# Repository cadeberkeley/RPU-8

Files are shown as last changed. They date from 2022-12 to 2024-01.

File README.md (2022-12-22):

# RPU-8
8-Bit Retro Processing Unit

Started on breadboards, inspired by Ben Eater's 8-bit CPU.  I got it more or less working on breadboards, and I am currently designing PCBs to make it more permanent and hopefully solve any power distribution or connection issues with the breadboard design.  I have sketched out a modular stacking design, so it will be easier to swap out for larger instruction/data memory or a larger program counter if I so please.

I am using KiCAD for schematic and PCB design.  Planning to source PCBs from JLCPCB.

TODO: Add images of breadboard.

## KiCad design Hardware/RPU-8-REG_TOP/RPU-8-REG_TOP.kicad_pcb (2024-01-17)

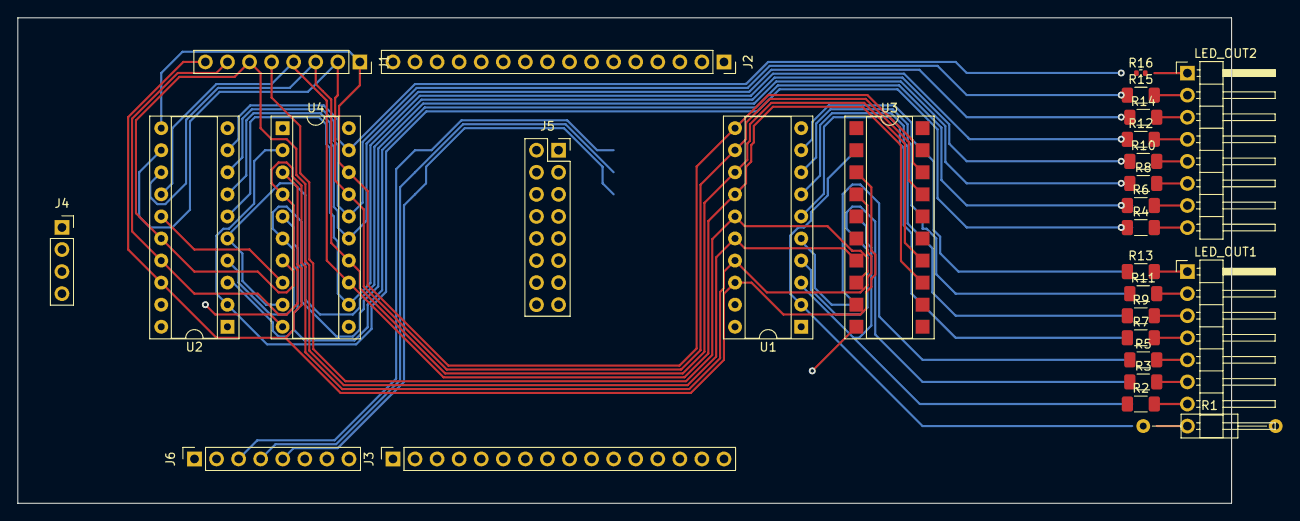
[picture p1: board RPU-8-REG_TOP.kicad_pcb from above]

Board: 2 copper layers, 139.7 x 55.9 mm, 28 parts (0 on the bottom side), 47 nets.

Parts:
J1: DATA_BUS; PinSocket_1x08_P2.54mm_Vertical
J2: ADDR_BUS; PinSocket_1x16_P2.54mm_Vertical
J3: CTRL_BUS; PinSocket_1x16_P2.54mm_Vertical
J4: Conn_01x03_Female; PinSocket_1x04_P2.54mm_Vertical
J5: REG_CTRL; PinSocket_2x08_P2.54mm_Vertical
J6: INST_BITS; PinSocket_1x08_P2.54mm_Vertical
LED_OUT1, LED_OUT2: LEDs; PinHeader_1x08_P2.54mm_Horizontal
R1: 220Ω; R_Axial_DIN0207_L6.3mm_D2.5mm_P15.24mm_Horizontal
R2, R3, R4, R5, R6, R7, R8, R9, R10, R11, R12, R13, R14, R15: 220Ω; R_1206_3216Metric_Pad1.30x1.75mm_HandSolder
R16: 220Ω; R_0402_1005Metric
U1, U2: 74HC245; DIP-20_W7.62mm_Socket
U3: 74HC377; DIP-20_W7.62mm_SMDSocket_SmallPads
U4: 74HC377; DIP-20_W7.62mm_Socket

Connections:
+5V: J4.3, U1.1 (A->B), U1.20 (VCC), U2.1 (A->B), U2.20 (VCC), U3.20 (VCC), U4.20 (VCC)
CLK: J4.1, U3.11 (CP), U4.11 (CP)
D0: J1.1, U1.11 (B7), U2.11 (B7), U3.18 (D7), U4.18 (D7)
D1: J1.2, U1.12 (B6), U2.12 (B6), U3.17 (D6), U4.17 (D6)
D2: J1.3, U1.13 (B5), U2.13 (B5), U3.14 (D5), U4.14 (D5)
D3: J1.4, U1.14 (B4), U2.14 (B4), U3.13 (D4), U4.13 (D4)
D4: J1.5, U1.15 (B3), U2.15 (B3), U3.8 (D3), U4.8 (D3)
D5: J1.6, U1.16 (B2), U2.16 (B2), U3.7 (D2), U4.7 (D2)
D6: J1.7, U1.17 (B1), U2.17 (B1), U3.4 (D1), U4.4 (D1)
D7: J1.8, U1.18 (B0), U2.18 (B0), U3.3 (D0), U4.3 (D0)
GND: J4.2, U1.10 (GND), U2.10 (GND), U3.10 (GND), U4.10 (GND)
unnamed: LED_OUT1.1 (R0), R13.2
unnamed: LED_OUT1.2 (R1), R11.2
unnamed: LED_OUT1.3 (R2), R9.2
unnamed: LED_OUT1.4 (R3), R7.2
unnamed: LED_OUT1.5 (R4), R5.2
unnamed: LED_OUT1.6 (R5), R3.2
unnamed: LED_OUT1.7 (R6), R2.2
unnamed: LED_OUT1.8 (R7), R1.2
unnamed: LED_OUT2.1 (R0), R16.2
unnamed: LED_OUT2.2 (R1), R15.2
unnamed: LED_OUT2.3 (R2), R14.2
unnamed: LED_OUT2.4 (R3), R12.2
unnamed: LED_OUT2.5 (R4), R10.2
unnamed: LED_OUT2.6 (R5), R8.2
unnamed: LED_OUT2.7 (R6), R6.2
unnamed: LED_OUT2.8 (R7), R4.2
unnamed: R1.1, U1.2 (A0), U3.2 (Q0)
unnamed: R2.1, U1.3 (A1), U3.5 (Q1)
unnamed: R3.1, U1.4 (A2), U3.6 (Q2)
unnamed: R4.1, U2.2 (A0), U4.2 (Q0)
unnamed: R5.1, U1.5 (A3), U3.9 (Q3)
unnamed: R6.1, U2.3 (A1), U4.5 (Q1)
unnamed: R7.1, U1.6 (A4), U3.12 (Q4)
unnamed: R8.1, U2.4 (A2), U4.6 (Q2)
unnamed: R9.1, U1.7 (A5), U3.15 (Q5)
unnamed: R10.1, U2.5 (A3), U4.9 (Q3)
unnamed: R11.1, U1.8 (A6), U3.16 (Q6)
unnamed: R12.1, U2.6 (A4), U4.12 (Q4)
unnamed: R13.1, U1.9 (A7), U3.19 (Q7)
unnamed: R14.1, U2.7 (A5), U4.15 (Q5)
unnamed: R15.1, U2.8 (A6), U4.16 (Q6)
unnamed: R16.1, U2.9 (A7), U4.19 (Q7)
~R0_IN: J5.1, U3.1 (~E)
~R0_OUT: J5.2, U1.19 (CE)
~R1_IN: J5.3, U4.1 (~E)
~R1_OUT: J5.4, U2.19 (CE)

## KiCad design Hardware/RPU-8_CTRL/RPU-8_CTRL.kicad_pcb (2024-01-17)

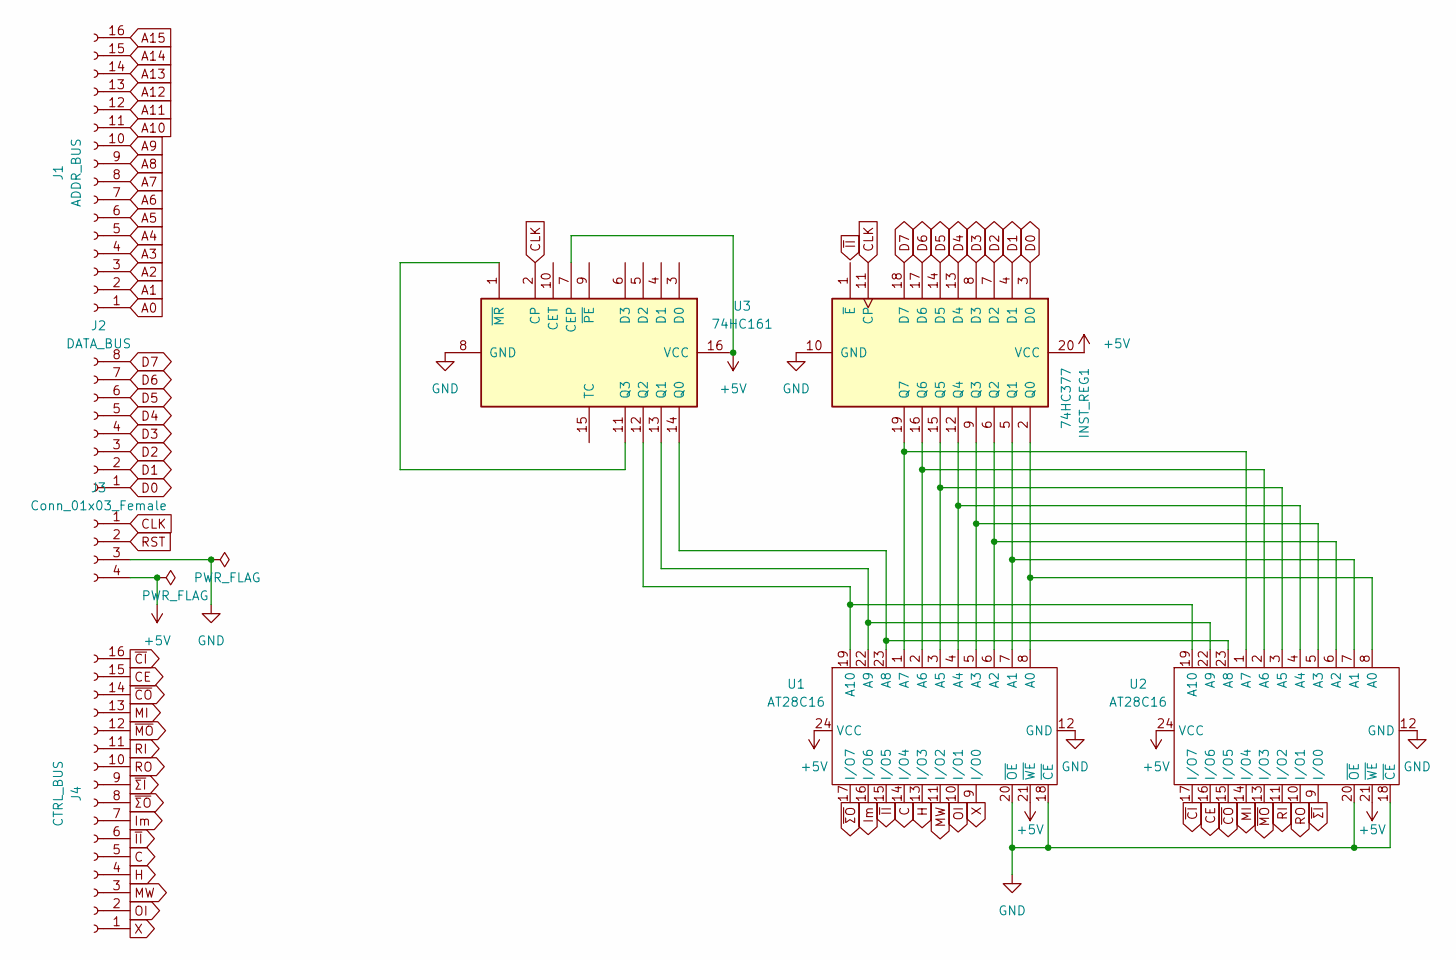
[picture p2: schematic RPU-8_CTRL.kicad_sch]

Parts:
INST_REG1: 74HC377; DIP-20_W7.62mm_Socket
J1: ADDR_BUS; PinSocket_1x16_P2.54mm_Vertical
J2: DATA_BUS; PinSocket_1x08_P2.54mm_Vertical
J3: Conn_01x03_Female; PinSocket_1x04_P2.54mm_Vertical
J4: CTRL_BUS; PinSocket_1x16_P2.54mm_Vertical
U1, U2: AT28C16; DIP-24_W15.24mm_Socket
U3: 74HC161; DIP-16_W7.62mm_Socket

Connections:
+5V: INST_REG1.20 (VCC), J3.4, U1.21 (~WE), U1.24 (VCC), U2.21 (~WE), U2.24 (VCC), U3.7 (CEP), U3.16 (VCC)
A0: J1.1
A1: J1.2
A2: J1.3
A3: J1.4
A4: J1.5
A5: J1.6
A6: J1.7
A7: J1.8
A8: J1.9
A9: J1.10
A10: J1.11
A11: J1.12
A12: J1.13
A13: J1.14
A14: J1.15
A15: J1.16
C: J4.5, U1.14 (I/O4)
CE: J4.15, U2.16 (I/O6)
CLK: INST_REG1.11 (CP), J3.1, U3.2 (CP)
D0: INST_REG1.3 (D0), J2.1
D1: INST_REG1.4 (D1), J2.2
D2: INST_REG1.7 (D2), J2.3
D3: INST_REG1.8 (D3), J2.4
D4: INST_REG1.13 (D4), J2.5
D5: INST_REG1.14 (D5), J2.6
D6: INST_REG1.17 (D6), J2.7
D7: INST_REG1.18 (D7), J2.8
GND: INST_REG1.10 (GND), J3.3, U1.12 (GND), U1.18 (~CE), U1.20 (~OE), U2.12 (GND), U2.18 (~CE), U2.20 (~OE), U3.8 (GND)
H: J4.4, U1.13 (I/O3)
Im: J4.7, U1.16 (I/O6)
MI: J4.13, U2.14 (I/O4)
MW: J4.3, U1.11 (I/O2)
unnamed: INST_REG1.19 (Q7), U1.1 (A7), U2.1 (A7)
unnamed: INST_REG1.16 (Q6), U1.2 (A6), U2.2 (A6)
unnamed: INST_REG1.15 (Q5), U1.3 (A5), U2.3 (A5)
unnamed: INST_REG1.12 (Q4), U1.4 (A4), U2.4 (A4)
unnamed: INST_REG1.9 (Q3), U1.5 (A3), U2.5 (A3)
unnamed: INST_REG1.6 (Q2), U1.6 (A2), U2.6 (A2)
unnamed: INST_REG1.5 (Q1), U1.7 (A1), U2.7 (A1)
unnamed: INST_REG1.2 (Q0), U1.8 (A0), U2.8 (A0)
unnamed: U1.22 (A9), U2.22 (A9), U3.13 (Q1)
unnamed: U1.23 (A8), U2.23 (A8), U3.14 (Q0)
unnamed: U1.19 (A10), U2.19 (A10), U3.12 (Q2)
unnamed: U3.1 (~MR), U3.11 (Q3)
OI: J4.2, U1.10 (I/O1)
RI: J4.11, U2.11 (I/O2)
RO: J4.10, U2.10 (I/O1)
RST: J3.2
X: J4.1, U1.9 (I/O0)
~CI: J4.16, U2.17 (I/O7)
~CO: J4.14, U2.15 (I/O5)
~II: J4.6, U1.15 (I/O5)
~MO: J4.12, U2.13 (I/O3)
~ΣI: J4.9, U2.9 (I/O0)
~ΣO: J4.8, U1.17 (I/O7)

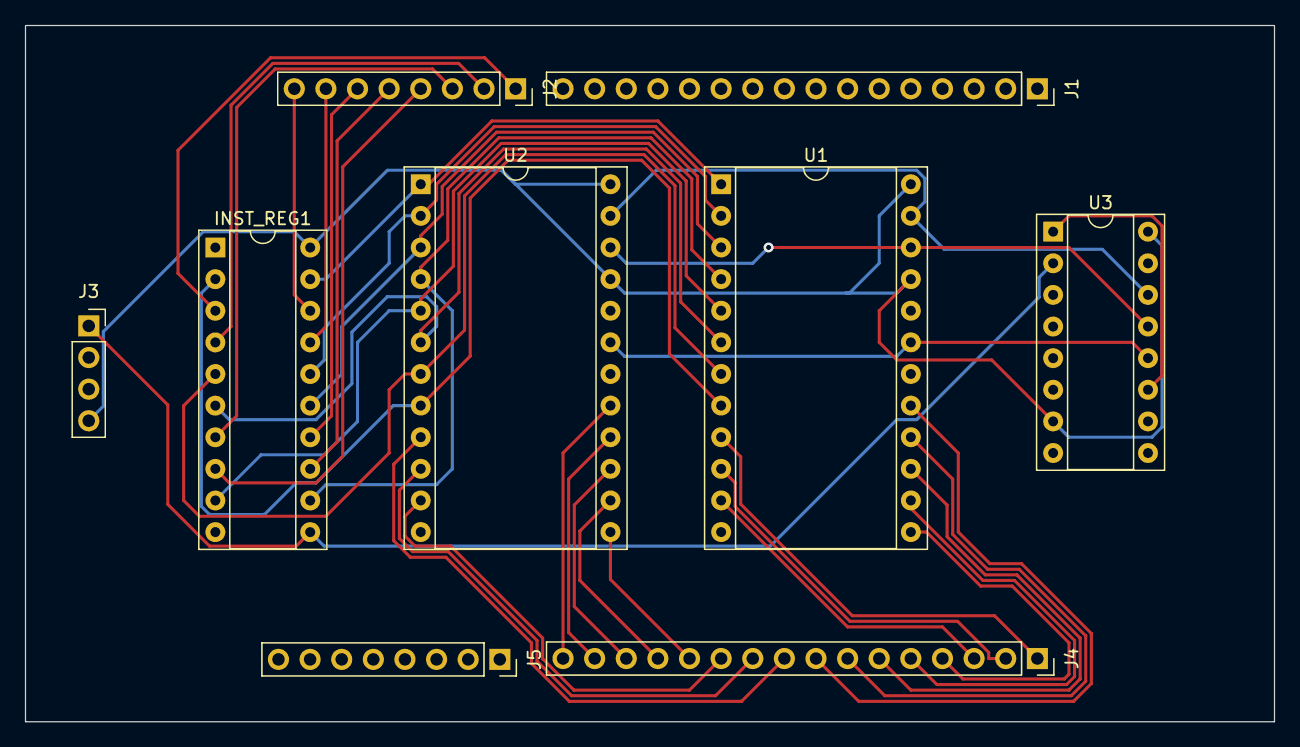
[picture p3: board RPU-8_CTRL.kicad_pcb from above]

Board: 2 copper layers, 100.3 x 55.9 mm, 9 parts (0 on the bottom side), 39 nets.

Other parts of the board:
J5: INST_REG; PinSocket_1x08_P2.54mm_Vertical

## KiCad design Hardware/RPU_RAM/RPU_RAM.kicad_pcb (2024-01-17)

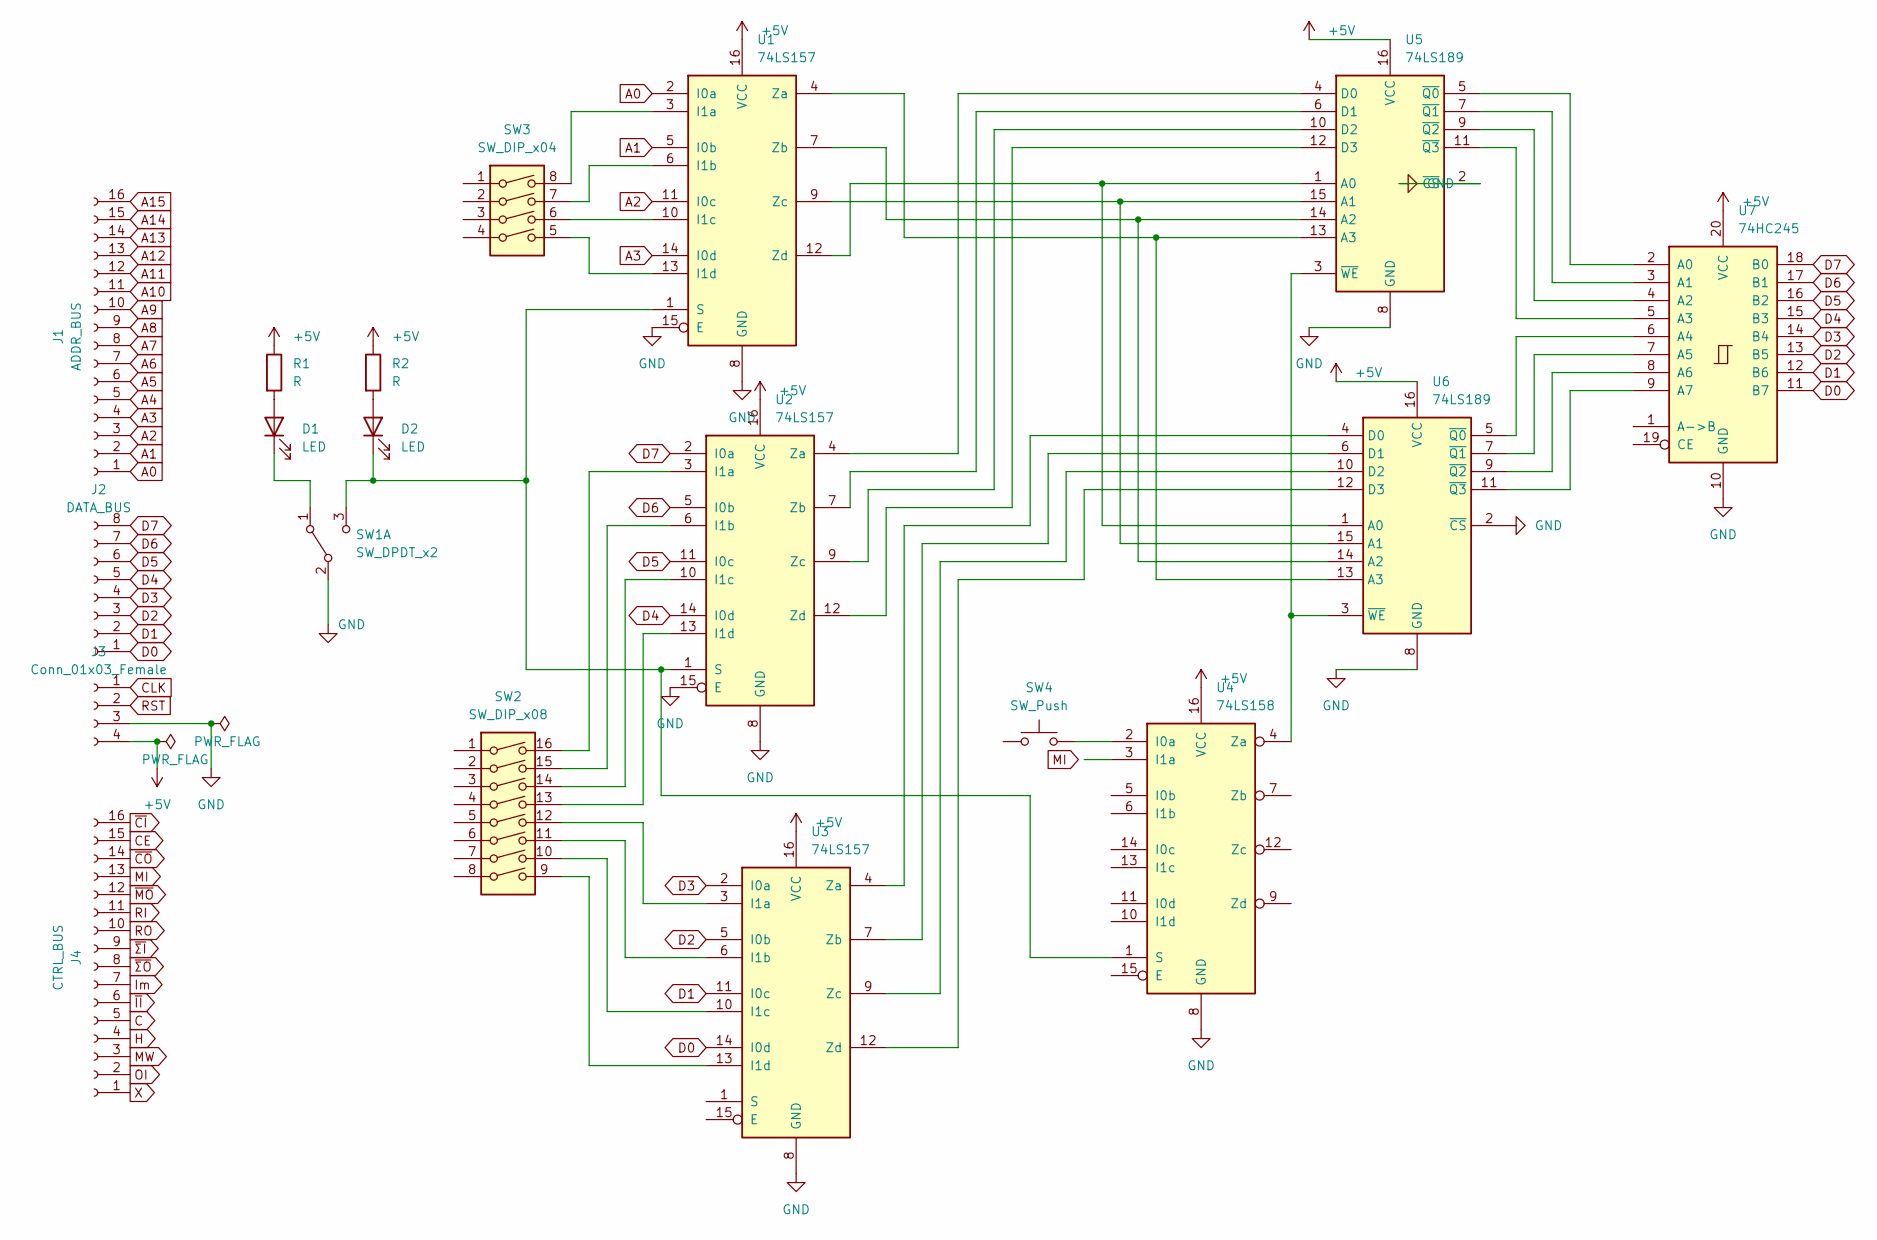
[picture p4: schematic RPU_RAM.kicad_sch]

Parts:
D1, D2: LED; LED_D3.0mm_Horizontal_O1.27mm_Z2.0mm
J1: ADDR_BUS; PinSocket_1x16_P2.54mm_Vertical
J2: DATA_BUS; PinSocket_1x08_P2.54mm_Vertical
J3: Conn_01x03_Female; PinSocket_1x04_P2.54mm_Vertical
J4: CTRL_BUS; PinSocket_1x16_P2.54mm_Vertical
R1, R2: R; R_0402_1005Metric
SW1: SW_DPDT_x2; SW_PUSH_6mm
SW2: SW_DIP_x08; DIP-16_W7.62mm
SW3: SW_DIP_x04; DIP-8_W7.62mm
SW4: SW_Push; SW_Slide_1P2T_CK_OS102011MS2Q
U1, U2, U3: 74LS157; DIP-16_W7.62mm
U4: 74LS158; DIP-16_W7.62mm
U5, U6: 74LS189; DIP-16_W7.62mm
U7: 74HC245; DIP-20_W7.62mm

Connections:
+5V: J3.4, R1.1, R2.1, U1.16 (VCC), U2.16 (VCC), U3.16 (VCC), U4.16 (VCC), U5.16 (VCC), U6.16 (VCC), U7.20 (VCC)
A0: J1.1, U1.2 (I0a)
A1: J1.2, U1.5 (I0b)
A2: J1.3, U1.11 (I0c)
A3: J1.4, U1.14 (I0d)
A4: J1.5
A5: J1.6
A6: J1.7
A7: J1.8
A8: J1.9
A9: J1.10
A10: J1.11
A11: J1.12
A12: J1.13
A13: J1.14
A14: J1.15
A15: J1.16
C: J4.5
CE: J4.15
CLK: J3.1
D0: J2.1, U3.14 (I0d), U7.11 (B7)
D1: J2.2, U3.11 (I0c), U7.12 (B6)
D2: J2.3, U3.5 (I0b), U7.13 (B5)
D3: J2.4, U3.2 (I0a), U7.14 (B4)
D4: J2.5, U2.14 (I0d), U7.15 (B3)
D5: J2.6, U2.11 (I0c), U7.16 (B2)
D6: J2.7, U2.5 (I0b), U7.17 (B1)
D7: J2.8, U2.2 (I0a), U7.18 (B0)
GND: J3.3, SW1.2 (B), U1.8 (GND), U1.15 (E), U2.8 (GND), U2.15 (E), U3.8 (GND), U4.8 (GND), U5.2 (~CS), U5.8 (GND), U6.2 (~CS), U6.8 (GND), U7.10 (GND)
H: J4.4
Im: J4.7
MI: J4.13
MW: J4.3
unnamed: D1.1 (K), SW1.1 (A)
unnamed: D1.2 (A), R1.2
unnamed: D2.1 (K), SW1.3 (C), U1.1 (S), U2.1 (S), U4.1 (S)
unnamed: D2.2 (A), R2.2
unnamed: SW2.9, U3.13 (I1d)
unnamed: SW2.10, U3.10 (I1c)
unnamed: SW2.11, U3.6 (I1b)
unnamed: SW2.12, U3.3 (I1a)
unnamed: SW2.13, U2.13 (I1d)
unnamed: SW2.14, U2.10 (I1c)
unnamed: SW2.15, U2.6 (I1b)
unnamed: SW2.16, U2.3 (I1a)
unnamed: SW3.5, U1.13 (I1d)
unnamed: SW3.6, U1.10 (I1c)
unnamed: SW3.7, U1.6 (I1b)
unnamed: SW3.8, U1.3 (I1a)
unnamed: SW4.2, U4.2 (I0a)
unnamed: U1.4 (Za), U5.13 (A3), U6.13 (A3)
unnamed: U1.7 (Zb), U5.14 (A2), U6.14 (A2)
unnamed: U1.9 (Zc), U5.15 (A1), U6.15 (A1)
unnamed: U1.12 (Zd), U5.1 (A0), U6.1 (A0)
unnamed: U2.4 (Za), U5.4 (D0)
unnamed: U2.7 (Zb), U5.6 (D1)
unnamed: U2.9 (Zc), U5.10 (D2)
unnamed: U2.12 (Zd), U5.12 (D3)
unnamed: U3.4 (Za), U6.4 (D0)
unnamed: U3.7 (Zb), U6.6 (D1)
unnamed: U3.9 (Zc), U6.10 (D2)
unnamed: U3.12 (Zd), U6.12 (D3)
unnamed: U4.4 (Za), U5.3 (~WE), U6.3 (~WE)
unnamed: U5.5 (~Q0), U7.2 (A0)
unnamed: U5.7 (~Q1), U7.3 (A1)
unnamed: U5.9 (~Q2), U7.4 (A2)
unnamed: U5.11 (~Q3), U7.5 (A3)
unnamed: U6.5 (~Q0), U7.6 (A4)
unnamed: U6.7 (~Q1), U7.7 (A5)
unnamed: U6.9 (~Q2), U7.8 (A6)
unnamed: U6.11 (~Q3), U7.9 (A7)
OI: J4.2
RI: J4.11
RO: J4.10
RST: J3.2
X: J4.1
~CI: J4.16
~CO: J4.14
~II: J4.6
~MO: J4.12
~ΣI: J4.9
~ΣO: J4.8

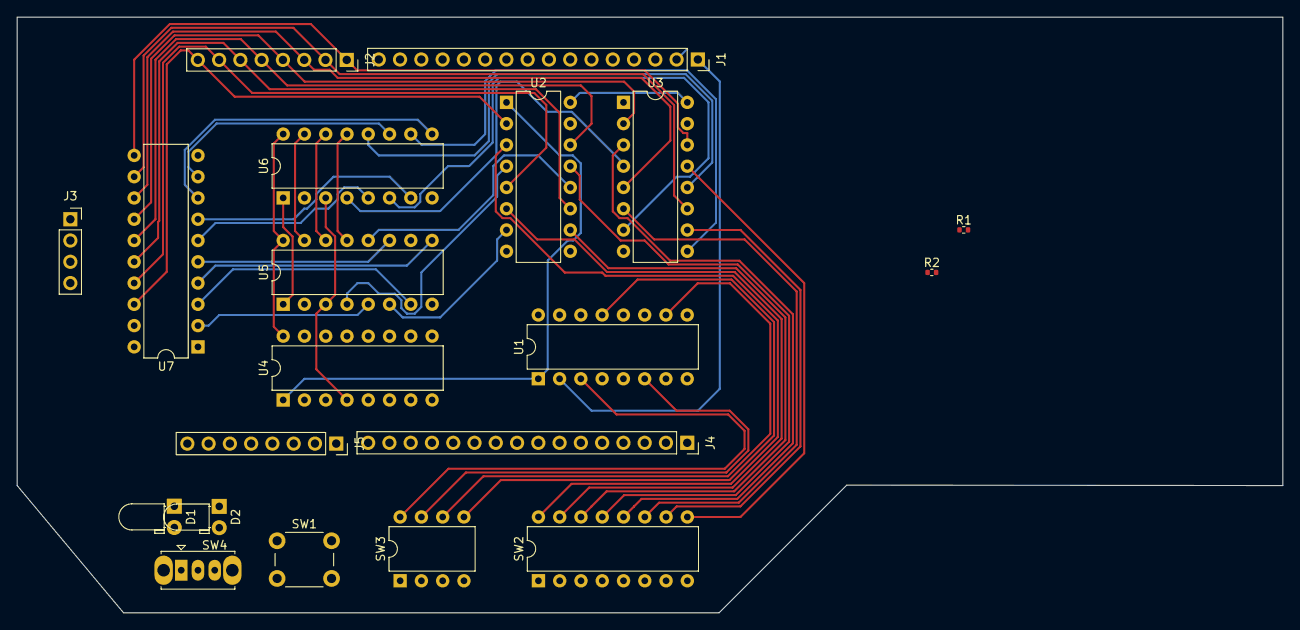
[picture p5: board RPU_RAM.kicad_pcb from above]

Board: 2 copper layers, 151.1 x 71.1 mm, 20 parts (0 on the bottom side), 52 nets.

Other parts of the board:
J5: INST_REG; PinSocket_1x08_P2.54mm_Vertical

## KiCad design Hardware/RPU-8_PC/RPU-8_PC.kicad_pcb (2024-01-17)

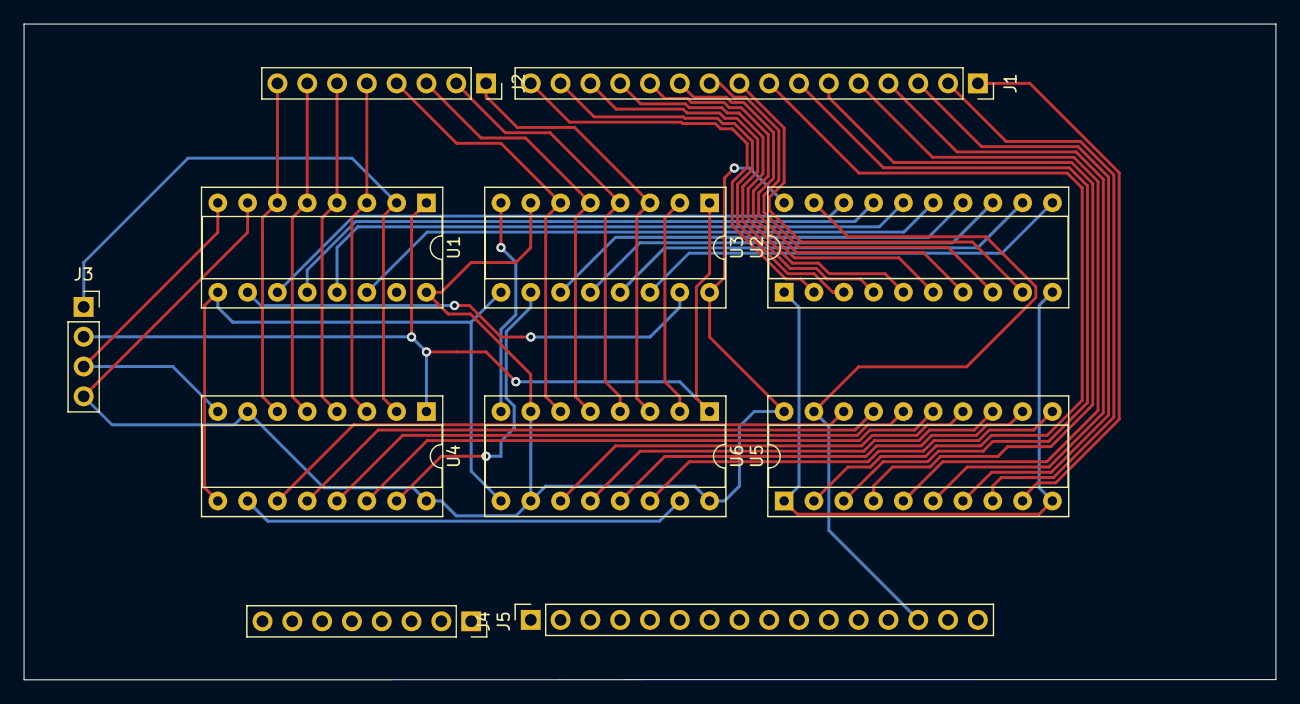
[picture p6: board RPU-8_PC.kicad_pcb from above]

Board: 2 copper layers, 106.7 x 55.9 mm, 11 parts (0 on the bottom side), 49 nets.

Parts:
J1: ADDR_BUS; PinSocket_1x16_P2.54mm_Vertical
J2: DATA_BUS; PinSocket_1x08_P2.54mm_Vertical
J3: Conn_01x03_Female; PinSocket_1x04_P2.54mm_Vertical
J4: CTRL_BUS; PinSocket_1x16_P2.54mm_Vertical
J5: INST_REG; PinSocket_1x08_P2.54mm_Vertical
U1, U3, U4, U6: 74HC161; DIP-16_W7.62mm_Socket
U2, U5: 74HC245; DIP-20_W7.62mm_Socket

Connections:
+5V: J3.4, U1.7 (CEP), U1.16 (VCC), U2.20 (VCC), U3.7 (CEP), U3.16 (VCC), U4.7 (CEP), U4.16 (VCC), U5.20 (VCC), U6.7 (CEP), U6.10 (CET), U6.16 (VCC)
A0: J1.1, U5.9 (A7)
A1: J1.2, U5.8 (A6)
A2: J1.3, U5.7 (A5)
A3: J1.4, U5.6 (A4)
A4: J1.5, U5.5 (A3)
A5: J1.6, U5.4 (A2)
A6: J1.7, U5.3 (A1)
A7: J1.8, U5.2 (A0)
A8: J1.9, U2.9 (A7)
A9: J1.10, U2.8 (A6)
A10: J1.11, U2.7 (A5)
A11: J1.12, U2.6 (A4)
A12: J1.13, U2.5 (A3)
A13: J1.14, U2.4 (A2)
A14: J1.15, U2.3 (A1)
A15: J1.16, U2.2 (A0)
CLK: J3.1, U1.2 (CP), U3.2 (CP), U4.2 (CP), U6.2 (CP)
D0: J2.1, U3.3 (D0), U6.3 (D0)
D1: J2.2, U3.4 (D1), U6.4 (D1)
D2: J2.3, U3.5 (D2), U6.5 (D2)
D3: J2.4, U3.6 (D3), U6.6 (D3)
D4: J2.5, U1.3 (D0), U4.3 (D0)
D5: J2.6, U1.4 (D1), U4.4 (D1)
D6: J2.7, U1.5 (D2), U4.5 (D2)
D7: J2.8, U1.6 (D3), U4.6 (D3)
GND: J3.3, U1.8 (GND), U2.1 (A->B), U2.10 (GND), U3.8 (GND), U4.8 (GND), U5.1 (A->B), U5.10 (GND), U6.8 (GND)
unnamed: U1.10 (CET), U3.15 (TC)
unnamed: U1.11 (Q3), U2.18 (B0)
unnamed: U1.12 (Q2), U2.17 (B1)
unnamed: U1.13 (Q1), U2.16 (B2)
unnamed: U1.14 (Q0), U2.15 (B3)
unnamed: U2.11 (B7), U3.14 (Q0)
unnamed: U2.12 (B6), U3.13 (Q1)
unnamed: U2.13 (B5), U3.12 (Q2)
unnamed: U2.14 (B4), U3.11 (Q3)
unnamed: U3.10 (CET), U4.15 (TC)
unnamed: U4.10 (CET), U6.15 (TC)
unnamed: U4.11 (Q3), U5.18 (B0)
unnamed: U4.12 (Q2), U5.17 (B1)
unnamed: U4.13 (Q1), U5.16 (B2)
unnamed: U4.14 (Q0), U5.15 (B3)
unnamed: U5.11 (B7), U6.14 (Q0)
unnamed: U5.12 (B6), U6.13 (Q1)
unnamed: U5.13 (B5), U6.12 (Q2)
unnamed: U5.14 (B4), U6.11 (Q3)
RST: J3.2, U1.1 (~MR), U3.1 (~MR), U4.1 (~MR), U6.1 (~MR)
~CIL: U1.9 (~PE), U3.9 (~PE), U4.9 (~PE), U6.9 (~PE)
~CO: J4.14, U2.19 (CE), U5.19 (CE)

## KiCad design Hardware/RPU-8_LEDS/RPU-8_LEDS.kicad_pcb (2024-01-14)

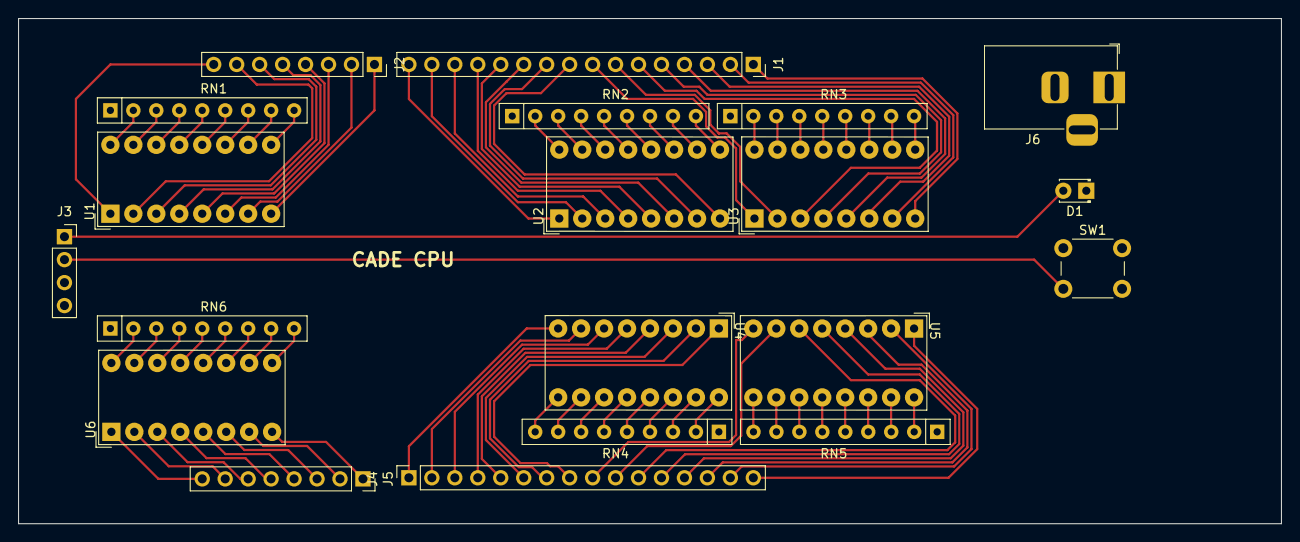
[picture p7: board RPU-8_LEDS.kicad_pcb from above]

Board: 4 copper layers, 139.7 x 55.9 mm, 20 parts (0 on the bottom side), 100 nets.

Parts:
D1: LED; LED_D1.8mm_W3.3mm_H2.4mm
J1: ADDR_BUS; PinSocket_1x16_P2.54mm_Vertical
J2: DATA_BUS; PinSocket_1x08_P2.54mm_Vertical
J3: Conn_01x03_Female; PinSocket_1x04_P2.54mm_Vertical
J4: CTRL_BUS; PinSocket_1x16_P2.54mm_Vertical
J5: INST_REG; PinSocket_1x08_P2.54mm_Vertical
J6: Barrel_Jack; BarrelJack_Horizontal
RN1, RN2, RN3, RN4, RN5, RN6: R_Network08; R_Array_SIP9
SW1: SW_Push; SW_PUSH_6mm
U1, U2, U3, U4, U5, U6: 8_Segment_LED_Bar_Graph; 8-SEGMENT_LED

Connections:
+5V: J3.4, J6.2, SW1.1
A0: J1.1, U3.8 (A)
A1: J1.2, U3.7 (A)
A2: J1.3, U3.6 (A)
A3: J1.4, U3.5 (A)
A4: J1.5, U3.4 (A)
A5: J1.6, U3.3 (A)
A6: J1.7, U3.2 (A)
A7: J1.8, U3.1 (A)
A8: J1.9, U2.8 (A)
A9: J1.10, U2.7 (A)
A10: J1.11, U2.6 (A)
A11: J1.12, U2.5 (A)
A12: J1.13, U2.4 (A)
A13: J1.14, U2.3 (A)
A14: J1.15, U2.2 (A)
A15: J1.16, U2.1 (A)
C: J4.5, U4.4 (A)
CE: J4.15, U5.2 (A)
CLK: D1.2 (A), J3.1
D0: J2.1, U1.8 (A)
D1: J2.2, U1.7 (A)
D2: J2.3, U1.6 (A)
D3: J2.4, U1.5 (A)
D4: J2.5, U1.4 (A)
D5: J2.6, U1.3 (A)
D6: J2.7, U1.2 (A)
D7: J2.8, U1.1 (A)
GND: D1.1 (K), J3.3, J6.1, RN1.1 (common), RN2.1 (common), RN3.1 (common), RN4.1 (common), RN5.1 (common), RN6.1 (common)
H: J4.4, U4.5 (A)
I0: J5.1, U6.8 (A)
I1: J5.2, U6.7 (A)
I3: J5.3, U6.6 (A)
I4: J5.4, U6.5 (A)
I5: J5.5, U6.4 (A)
I6: J5.6, U6.3 (A)
I7: J5.7, U6.2 (A)
I8: J5.8, U6.1 (A)
Im: J4.7, U4.2 (A)
MI: J4.13, U5.4 (A)
MW: J4.3, U4.6 (A)
unnamed: RN1.2 (R1), U1.16 (K)
unnamed: RN1.3 (R2), U1.15 (K)
unnamed: RN1.4 (R3), U1.14 (K)
unnamed: RN1.5 (R4), U1.13 (K)
unnamed: RN1.6 (R5), U1.12 (K)
unnamed: RN1.7 (R6), U1.11 (K)
unnamed: RN1.8 (R7), U1.10 (K)
unnamed: RN1.9 (R8), U1.9 (K)
unnamed: RN2.2 (R1), U2.16 (K)
unnamed: RN2.3 (R2), U2.15 (K)
unnamed: RN2.4 (R3), U2.14 (K)
unnamed: RN2.5 (R4), U2.13 (K)
unnamed: RN2.6 (R5), U2.12 (K)
unnamed: RN2.7 (R6), U2.11 (K)
unnamed: RN2.8 (R7), U2.10 (K)
unnamed: RN2.9 (R8), U2.9 (K)
unnamed: RN3.2 (R1), U3.16 (K)
unnamed: RN3.3 (R2), U3.15 (K)
unnamed: RN3.4 (R3), U3.14 (K)
unnamed: RN3.5 (R4), U3.13 (K)
unnamed: RN3.6 (R5), U3.12 (K)
unnamed: RN3.7 (R6), U3.11 (K)
unnamed: RN3.8 (R7), U3.10 (K)
unnamed: RN3.9 (R8), U3.9 (K)
unnamed: RN4.2 (R1), U4.16 (K)
unnamed: RN4.3 (R2), U4.15 (K)
unnamed: RN4.4 (R3), U4.14 (K)
unnamed: RN4.5 (R4), U4.13 (K)
unnamed: RN4.6 (R5), U4.12 (K)
unnamed: RN4.7 (R6), U4.11 (K)
unnamed: RN4.8 (R7), U4.10 (K)
unnamed: RN4.9 (R8), U4.9 (K)
unnamed: RN5.2 (R1), U5.16 (K)
unnamed: RN5.3 (R2), U5.15 (K)
unnamed: RN5.4 (R3), U5.14 (K)
unnamed: RN5.5 (R4), U5.13 (K)
unnamed: RN5.6 (R5), U5.12 (K)
unnamed: RN5.7 (R6), U5.11 (K)
unnamed: RN5.8 (R7), U5.10 (K)
unnamed: RN5.9 (R8), U5.9 (K)
unnamed: RN6.2 (R1), U6.16 (K)
unnamed: RN6.3 (R2), U6.15 (K)
unnamed: RN6.4 (R3), U6.14 (K)
unnamed: RN6.5 (R4), U6.13 (K)
unnamed: RN6.6 (R5), U6.12 (K)
unnamed: RN6.7 (R6), U6.11 (K)
unnamed: RN6.8 (R7), U6.10 (K)
unnamed: RN6.9 (R8), U6.9 (K)
OI: J4.2, U4.7 (A)
RI: J4.11, U5.6 (A)
RO: J4.10, U5.7 (A)
RST: J3.2, SW1.2
X: J4.1, U4.8 (A)
~CI: J4.16, U5.1 (A)
~CO: J4.14, U5.3 (A)
~II: J4.6, U4.3 (A)
~MO: J4.12, U5.5 (A)
~ΣI: J4.9, U5.8 (A)
~ΣO: J4.8, U4.1 (A)

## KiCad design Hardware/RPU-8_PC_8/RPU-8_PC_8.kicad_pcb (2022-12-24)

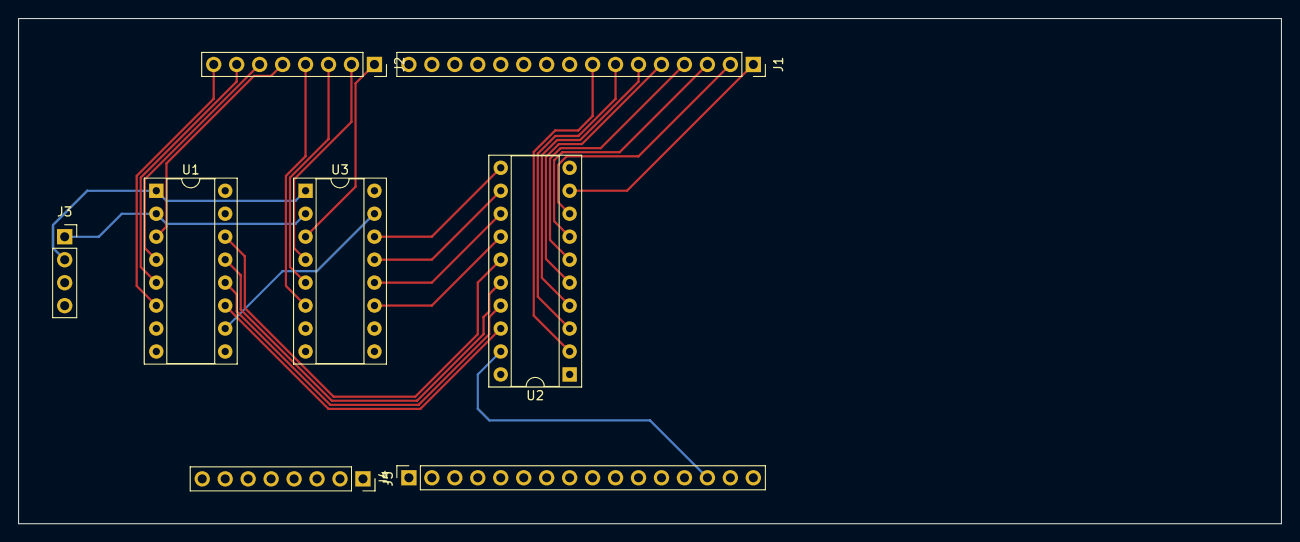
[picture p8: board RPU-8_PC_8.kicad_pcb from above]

Board: 4 copper layers, 139.7 x 55.9 mm, 8 parts (0 on the bottom side), 31 nets.

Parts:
J1: ADDR_BUS; PinSocket_1x16_P2.54mm_Vertical
J2: DATA_BUS; PinSocket_1x08_P2.54mm_Vertical
J3: Conn_01x03_Female; PinSocket_1x04_P2.54mm_Vertical
J4: CTRL_BUS; PinSocket_1x16_P2.54mm_Vertical
J5: INST_REG; PinSocket_1x08_P2.54mm_Vertical
U1, U3: 74HC161; DIP-16_W7.62mm_Socket
U2: 74HC245; DIP-20_W7.62mm_Socket

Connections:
+5V: J3.4, U1.7 (CEP), U1.16 (VCC), U2.20 (VCC), U3.7 (CEP), U3.10 (CET), U3.16 (VCC)
A0: J1.1, U2.9 (A7)
A1: J1.2, U2.8 (A6)
A2: J1.3, U2.7 (A5)
A3: J1.4, U2.6 (A4)
A4: J1.5, U2.5 (A3)
A5: J1.6, U2.4 (A2)
A6: J1.7, U2.3 (A1)
A7: J1.8, U2.2 (A0)
CLK: J3.1, U1.2 (CP), U3.2 (CP)
D0: J2.1, U3.3 (D0)
D1: J2.2, U3.4 (D1)
D2: J2.3, U3.5 (D2)
D3: J2.4, U3.6 (D3)
D4: J2.5, U1.3 (D0)
D5: J2.6, U1.4 (D1)
D6: J2.7, U1.5 (D2)
D7: J2.8, U1.6 (D3)
GND: J3.3, U1.8 (GND), U2.1 (A->B), U2.10 (GND), U3.8 (GND)
unnamed: U1.10 (CET), U3.15 (TC)
unnamed: U1.11 (Q3), U2.18 (B0)
unnamed: U1.12 (Q2), U2.17 (B1)
unnamed: U1.13 (Q1), U2.16 (B2)
unnamed: U1.14 (Q0), U2.15 (B3)
unnamed: U2.11 (B7), U3.14 (Q0)
unnamed: U2.12 (B6), U3.13 (Q1)
unnamed: U2.13 (B5), U3.12 (Q2)
unnamed: U2.14 (B4), U3.11 (Q3)
RST: J3.2, U1.1 (~MR), U3.1 (~MR)
~CIL: U1.9 (~PE), U3.9 (~PE)
~CO: J4.14, U2.19 (CE)

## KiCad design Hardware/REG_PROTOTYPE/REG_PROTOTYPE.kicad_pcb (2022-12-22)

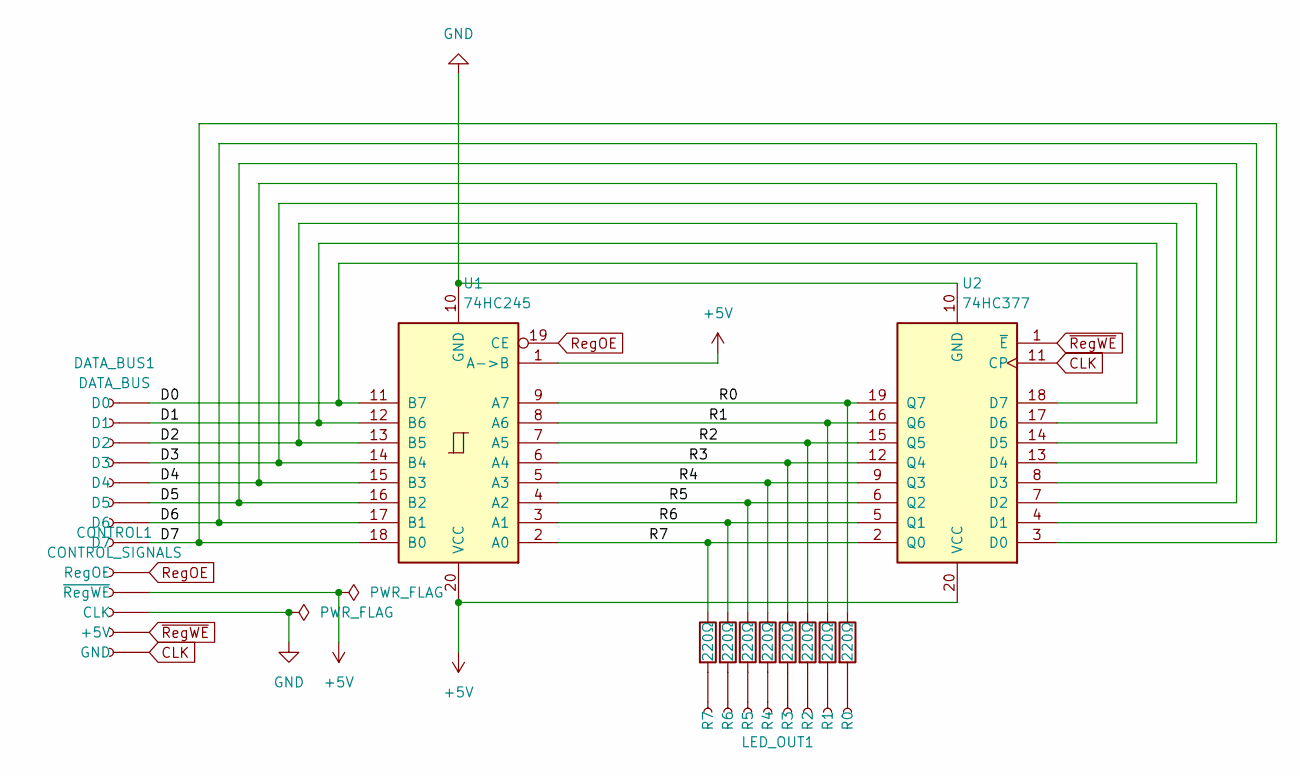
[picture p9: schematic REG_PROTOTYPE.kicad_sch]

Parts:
CONTROL1: CONTROL_SIGNALS; PinSocket_1x05_P2.54mm_Vertical
DATA_BUS1: DATA_BUS; PinSocket_1x08_P2.54mm_Vertical
LED_OUT1: LEDs; PinHeader_1x08_P2.54mm_Horizontal
R0, R1, R2, R3, R4, R5, R6, R7: 220Ω; R_1206_3216Metric_Pad1.30x1.75mm_HandSolder
U1: 74HC245; DIP-20_W7.62mm_Socket
U2: 74HC377; DIP-20_W7.62mm_Socket

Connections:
+5V: CONTROL1.2 (~RegWE), U1.1 (A->B), U1.20 (VCC), U2.20 (VCC)
/D0: DATA_BUS1.1 (D0), U1.11 (B7), U2.18 (D7)
/D1: DATA_BUS1.2 (D1), U1.12 (B6), U2.17 (D6)
/D2: DATA_BUS1.3 (D2), U1.13 (B5), U2.14 (D5)
/D3: DATA_BUS1.4 (D3), U1.14 (B4), U2.13 (D4)
/D4: DATA_BUS1.5 (D4), U1.15 (B3), U2.8 (D3)
/D5: DATA_BUS1.6 (D5), U1.16 (B2), U2.7 (D2)
/D6: DATA_BUS1.7 (D6), U1.17 (B1), U2.4 (D1)
/D7: DATA_BUS1.8 (D7), U1.18 (B0), U2.3 (D0)
/R0: R0.1, U1.9 (A7), U2.19 (Q7)
/R1: R7.1, U1.8 (A6), U2.16 (Q6)
/R2: R6.1, U1.7 (A5), U2.15 (Q5)
/R3: R5.1, U1.6 (A4), U2.12 (Q4)
/R4: R4.1, U1.5 (A3), U2.9 (Q3)
/R5: R3.1, U1.4 (A2), U2.6 (Q2)
/R6: R2.1, U1.3 (A1), U2.5 (Q1)
/R7: R1.1, U1.2 (A0), U2.2 (Q0)
CLK: CONTROL1.5 (GND), U2.11 (CP)
GND: CONTROL1.3 (CLK), U1.10 (GND), U2.10 (GND)
unnamed: LED_OUT1.1 (R0), R0.2
unnamed: LED_OUT1.2 (R1), R7.2
unnamed: LED_OUT1.3 (R2), R6.2
unnamed: LED_OUT1.4 (R3), R5.2
unnamed: LED_OUT1.5 (R4), R4.2
unnamed: LED_OUT1.6 (R5), R3.2
unnamed: LED_OUT1.7 (R6), R2.2
unnamed: LED_OUT1.8 (R7), R1.2
RegOE: CONTROL1.1 (RegOE), U1.19 (CE)
~RegWE: CONTROL1.4 (+5V), U2.1 (~E)

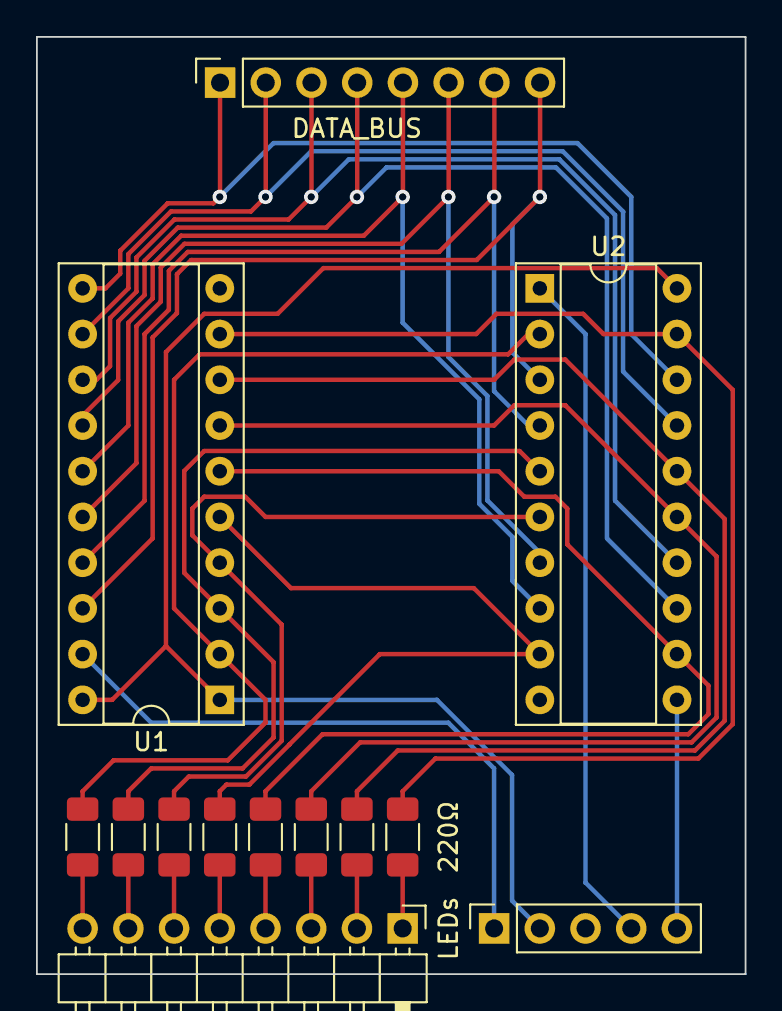
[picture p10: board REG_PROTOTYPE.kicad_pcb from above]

Board: 2 copper layers, 39.4 x 52.1 mm, 13 parts (0 on the bottom side), 29 nets.

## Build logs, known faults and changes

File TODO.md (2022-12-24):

### Todo
- [ ] Change all current PCB layouts to match new top layout (INST REG bus)
  - [x] Control
  - [x] Program Counter
  - [x] Register
- [ ] Add decoupling capacitors for every 74xx IC (Vias to GND/PWR planes)
- [ ] ISA
  - [ ] Figure out Load/Add Upper/Lower PC
- [ ] Modules
  - [ ] LEDs
    - [ ] Clock Signal LED
    - [ ] Reset Button
    - [ ] 5v Barrel Jack
  - [ ] Registers
    - [X] Bottom
    - [ ] Upper layers
  - [ ] Control
    - [ ] Add Instruction Register
    - [ ] 74HC161's for Addressing?
    - [ ] Add inverters
  - [ ] Clock
  - [ ] Memory
    - [ ] Input
      - [ ] Data
      - [ ] Address
      - [ ] Buttons & DIP Switches/Different PCB outline (On ends, like REG LEDs
    - [ ] RAM
  - [ ] ALU
  - [ ] EEPROM Programmer
  - [ ] 7-segment output display

### FUTURE
- [ ] ROM for IMEM, interchangeable module
- [ ] 2nd output port, could have as many as 8
- [ ] Interchangeable, less beefy ALU?

### CODE
- [ ] Simple "Assembler"
- [ ] Add ISA Docs/Schematic Images

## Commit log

2022-12-22 Putting this on GitHub
    [OSKI8_REGISTER-B_Cu.gbr, OSKI8_REGISTER-B_Mask.gbr, OSKI8_REGISTER-B_Paste.gbr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]
2022-12-24 CTRL Board Layout Fixed
    [OSKI8_REGISTER-B_Cu.gbr, OSKI8_REGISTER-B_Mask.gbr, OSKI8_REGISTER-B_Paste.gbr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]
2022-12-24 new 8-bit PC, add 16-bit later
    [RPU-8_PC.kicad_pcb, RPU-8_PC_8.kicad_pcb, RPU-8_PC_8.kicad_sch]
2022-12-24 fixed REG layout
    [RPU-8.kicad_pcb, RPU-8_REG.kicad_pcb, RPU-8_REG.kicad_sch]
2022-12-24 updated TODO.md
    [RPU-8_PC_8.kicad_sch]
2024-01-14 added images
    [RPU-7SEG_OUT.kicad_pcb, RPU-7SEG_OUT.kicad_sch, RPU-8_LEDS.kicad_pcb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]
2024-01-17 add .readthedocs.yaml
    [RPU-8-REG_TOP.kicad_pcb, RPU-8-REG_TOP.kicad_sch, RPU-8_CTRL.kicad_pcb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]
